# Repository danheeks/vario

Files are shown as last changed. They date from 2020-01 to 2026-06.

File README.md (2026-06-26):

# vario
  
paragliding vario with arduino nano, piezo sounder, bmp280 altimeter, 9V battery  
https://www.youtube.com/watch?v=9QVq33m_nv8

Instructions here https://github.com/danheeks/vario/tree/master/bmp280piezo <br />
One battery lasted me two summers of amateur paragliding, maybe 50hrs, including a flight of 202km in the UK! <br />
https://youtu.be/KGif6ZkmjKs?t=256  

You can buy a kit to make your own for £10, doesn't include postage

It includes: <br />
 <br />
Tin <br />
Arduino Nano <br />
BMP280 sensor <br />
Piezo Buzzer ( passive not active ) <br />
9V PP3 battery <br />
battery connector and wires <br />
On/Off switch <br />
version 7 PCB ( currently waiting for an order, available around 20th June 2026 ) <br />
Sticker for front of tin <br />
 <br />
Or you can buy a working vario £20, doesnt' include postage, ( I have 2 in stock 6th June 2026 ). <br />
 <br />
Email danheeks@gmail.com for enquiries and to check on stock <br />
  
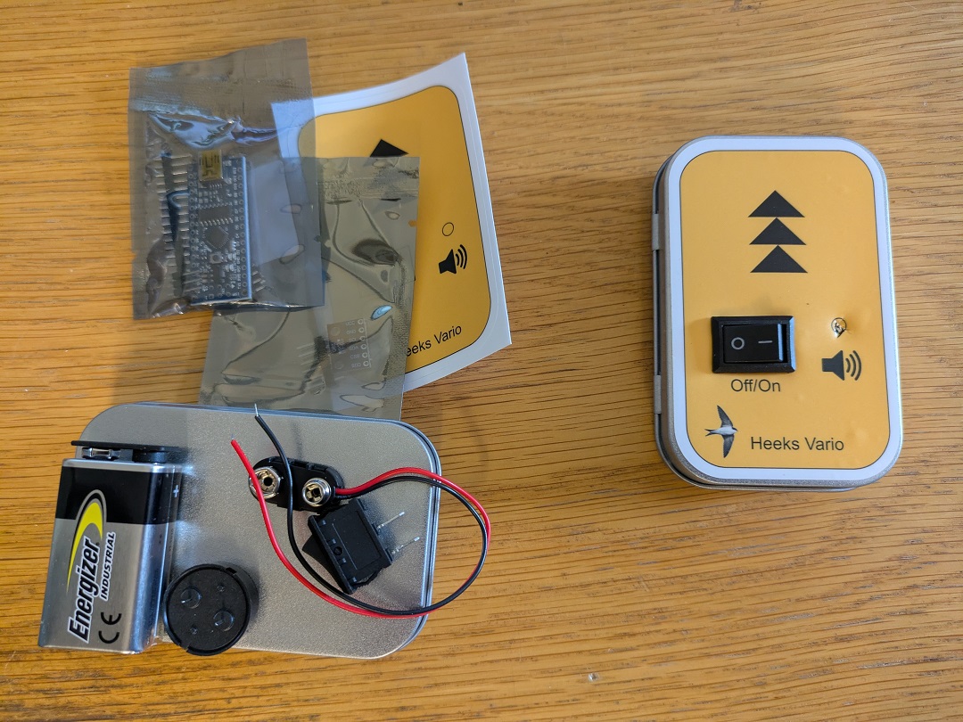
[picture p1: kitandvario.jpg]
Schematic Picture


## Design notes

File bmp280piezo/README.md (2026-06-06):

Vario using BMP280

Items needed

- Tin
- Arduino Nano
- BMP280 sensor
- Piezo Buzzer ( passive not active )
- 9V PP3 battery
- On/Off switch
- some wire

Wiring.

- Arduino GND to BMP280 GND
- Arduino 3.3V to BMP280 VDD
- Arduino A5 to BMP280 SCL
- Arduino A4 to BMP280 SDA
- Arduino D9 and D10 to the Piezo Buzzer ( see toneAC.h )
- Arduino VIN to battery + ( via on/off switch )
- Arduino GND to battery -

I measured 10mA standby current, so should theoretically last 55 hours.
One battery lasted me two summers of amateur paragliding, maybe 50hrs, including a flight of 202km in the UK! <br />
https://youtu.be/KGif6ZkmjKs?t=256  

Video of how to make this vario <br />
https://youtu.be/9QVq33m_nv8

Schematic Picture

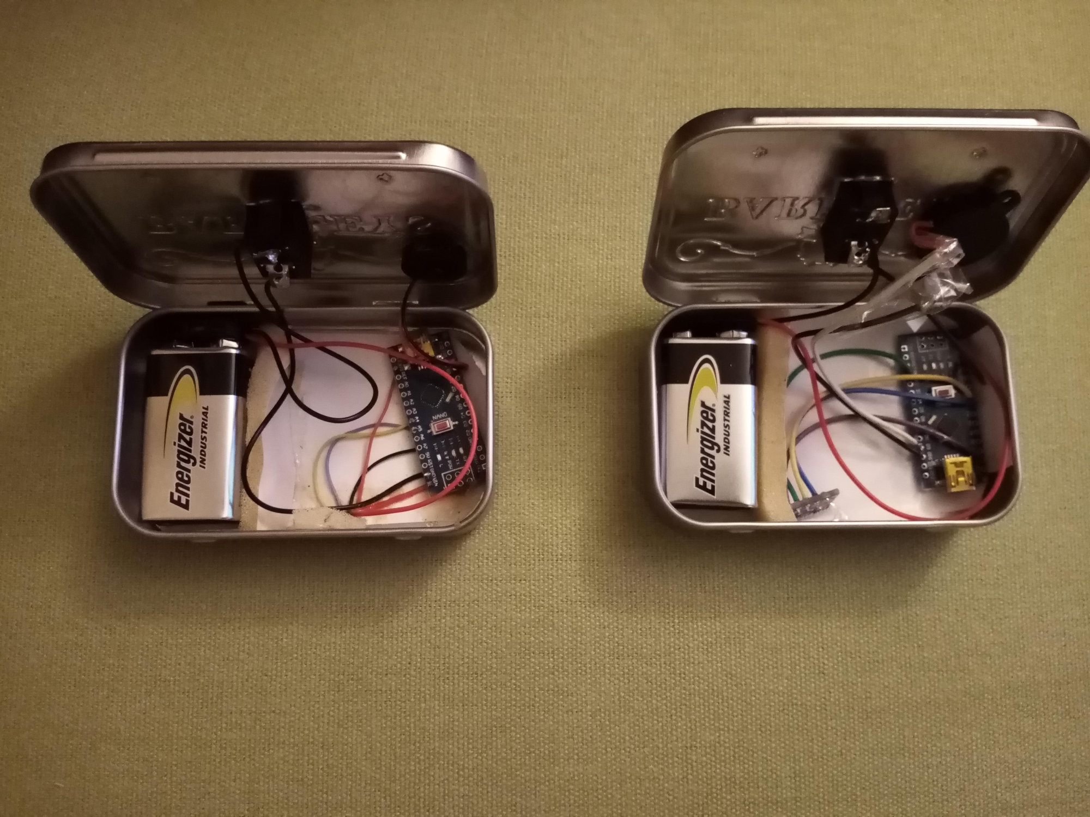
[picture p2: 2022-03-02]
variosopen.jpg

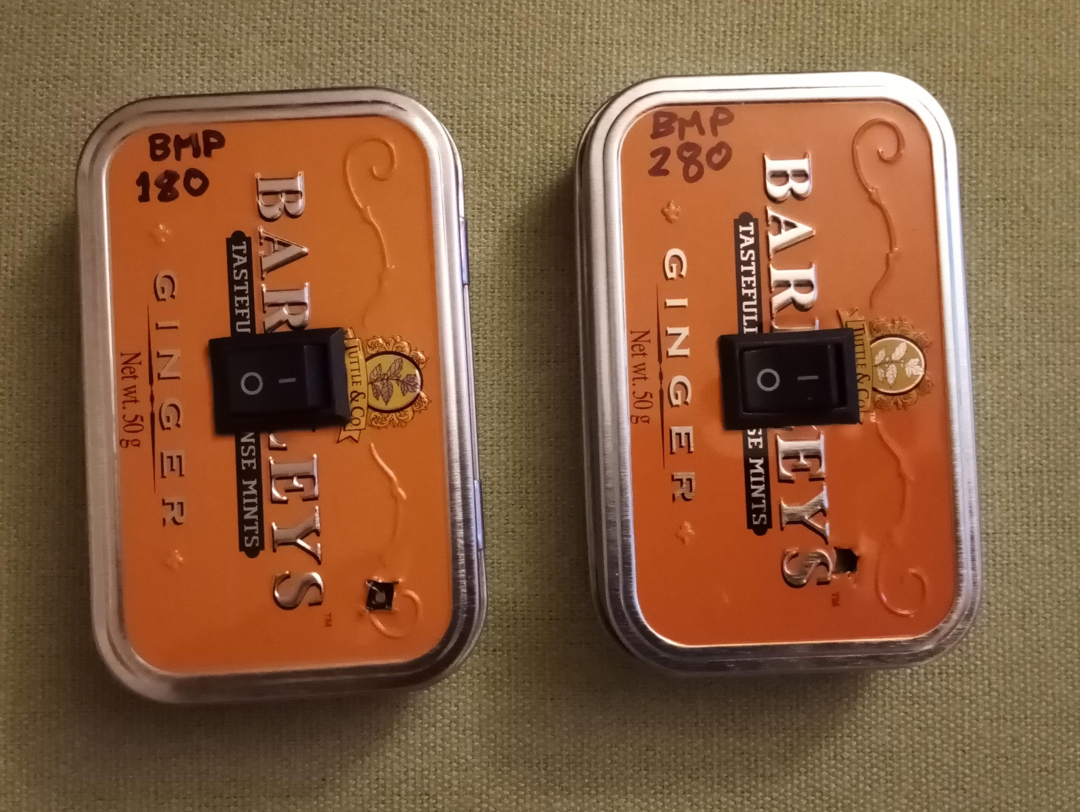
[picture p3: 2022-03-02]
varios.jpg

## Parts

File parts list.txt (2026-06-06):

Arduino Nano   £1.81
10PCS 35mm Piezo Elements buzzer Sounder   £0.25
BMP180        £1.00
on/off switch  £0.15
battery contacts £0.23
50g PLA

https://www.ebay.co.uk/itm/100-Pcs-Metal-Battery-Spring-Plate-Set-for-AA-AAA-Positive-Negative-Contact-r/143408425298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

and 

https://www.ebay.co.uk/itm/264527084049

total £3.78

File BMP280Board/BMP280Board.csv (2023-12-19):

# | Reference | Qty | Value | Footprint | DNP
1 | A1 | 1 | Arduino_Nano | Module:Arduino_Nano_WithMountingHoles
2 | C1, C2 | 2 | 100nF | Capacitor_SMD:CP_Elec_6.3x3.9
3 | R1, R2, R3, R4 | 4 | 10k | Resistor_SMD:R_0201_0603Metric
4 | U1 | 1 | BMP280 | Package_LGA:Bosch_LGA-8_2x2.5mm_P0.65mm_ClockwisePinNumbering

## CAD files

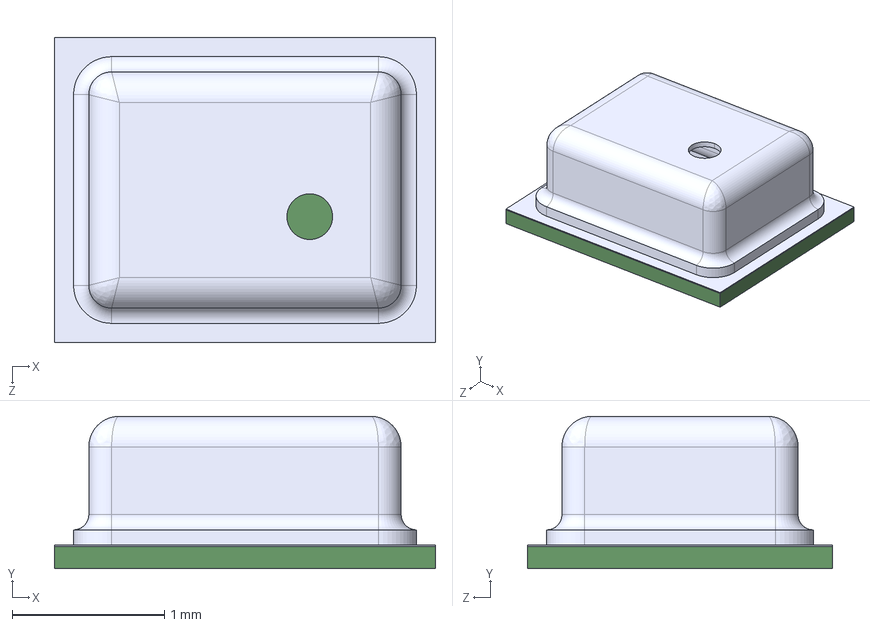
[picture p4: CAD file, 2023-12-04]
BMP280Board/BMP280/BMP280.step
2.50 x 1.00 x 2.00 mm

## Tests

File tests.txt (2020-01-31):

22-01-2020 Current draw 11.8mA
remove Serial calls
Current draw 11.7mA
removed the power led
current draw 9.8mA

added code: LowPower.powerDown(SLEEP_FOREVER, ADC_OFF, BOD_OFF);
current draw 1.4mA ( useless though :) )

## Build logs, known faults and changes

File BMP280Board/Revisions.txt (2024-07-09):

PCB ordered 8th Dec 2023
  Pads for resistors and capacitors were wrongly specified as "0201_0603Metric", when they should have been "0603_1608Metric_Pad0.98x0.95mm_HandSolder"
    ( the footprint had "0603" in the title, which is what I was looking for. I hadn't realized that the first number is inch, the second is mm )
  I had wrongly connected A4 ( SDA ) on Nano to SDO on BMP280. It should have been connected to SDI on BMP280.
  Likewise SDI was wrongly connected to a pull down to GND, but it should have been SDO getting pulled down to GND.
  I had connected a capacitor between A4 on Nano and GND, but it should have been connected between V3.3 and GND somewhere near the BMP280.
  I'd like to convert the footprint for the BMP280 to a hand solder footprint.
  The sensor was working, but the pressure change seemed a bit rubbish; I had to ascend the stairs at a run to get beeping. Damaged by the hot air gun or the flux maybe?

v2 PCB ordered 25th Dec 2023
   Assembled it 8th Jan 2024. Not working yet.

v3 
  Changed back to original sensor footprint, but had wrong wiring of sensor

v4 PCB orodered 27th Jan 2024
  I got one working and made a working vario. :) 
  Only of one the four boards that I made worked, though :(

v5
  switch to Attiny85

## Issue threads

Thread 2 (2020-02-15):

Wiring

m00nsp3ll, 2020-02-15:
Hello,
im going to build your vario but i need wiring scheme. Could you please share it.

Regards,

danheeks, 2020-02-15:
see in  vario/bmp180piezo/bmp180piezo.ino

/*
Hardware connections:
- (GND) to GND
+ (VDD) to 3.3V
SCL to A5
SDA to A4
*/

Also, I am connecting 3 x AA alkaline batteries via an on/off swithch to the 5V and GND on the arduino nano.

Is this enough?

m00nsp3ll, 2020-02-16:
thank you for the reply,

which pins should i wire the Piezo buzzer.

Regards,

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

--
Harun Sivaslı

danheeks, 2020-02-16:
D9 and D10 to the Piezo Buzzer.
I've just added a comment to the source code.

m00nsp3ll, 2020-02-16:
thank you very much,
i am going to build it and test.

regards

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

--
Harun Sivaslı

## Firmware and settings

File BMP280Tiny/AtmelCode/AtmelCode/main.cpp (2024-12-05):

// main.cpp Dan Heeks 20th October 2024
#include <avr/io.h>
#include <avr/interrupt.h>
#include <avr/sleep.h>
#include <avr/wdt.h>

// PIEZO_PINA PB1
// PIEZO_PINB PB2

#define SET_PIEZ0_A PORTB |= 0x02;
#define SET_PIEZ0_B PORTB |= 0x04;
#define CLR_PIEZ0_A PORTB &= 0xfd;
#define CLR_PIEZ0_B PORTB &= 0xfb;

#define F_CPU 8000000UL  // Set clock frequency to 8 MHz

#define BMP_280_ADDR 0x76

int delay_a = 0;
void delay(uint16_t ms)
{
	uint32_t i;
	uint32_t length = ms;
	length *= 600;
	
	for(i = 0; i<length; i++)
	{
		delay_a = 1;
	}
}

volatile uint16_t remaining_ms = 0;  // Variable to track the remaining delay time

// Watchdog Interrupt Service Routine (ISR)
ISR(WDT_vect) {
	if (remaining_ms >= 16) {
		remaining_ms -= 16;  // Decrease remaining time by 16 ms (WDT interval)
		} else {
		remaining_ms = 0;    // Ensure it doesn't go below zero
	}
}

void delay_ms(uint16_t ms) {
    remaining_ms = ms;

    // Set up the Watchdog Timer for 16 ms interrupts
    cli();  // Disable interrupts while configuring the WDT

    // Enable change of WDT settings
    wdt_reset();  // Reset the WDT
    MCUSR &= ~(1 << WDRF);  // Clear WDT reset flag
    WDTCSR |= (1 << WDCE) | (1 << WDE);  // Enable timed sequence for changing WDT settings

    // Set WDT to interrupt mode only, with the 16 ms timeout
    WDTCSR = (1 << WDIE);  // Set WDP0 = 0 (default), enabling the 16 ms timeout, enable WDT interrupt

    sei();  // Re-enable global interrupts

    // Enter low-power mode and wait for the delay to finish
    while (remaining_ms > 0) {
	    set_sleep_mode(SLEEP_MODE_IDLE);  // Power-down mode
	    sleep_mode();  // Go to sleep until WDT interrupt occurs
    }

    // Disable the Watchdog Timer after the delay is finished
    cli();
    wdt_reset();  // Reset the WDT again
    WDTCSR |= (1 << WDCE) | (1 << WDE);  // Enter WDT configuration mode
    WDTCSR = 0x00;  // Disable the WDT
    sei();  // Re-enable global interrupts
}

void led1_on()
{
	PORTB |= 0x20; // led1 on
}

void led1_off()
{
	PORTB &= 0xdf; // led1 off
}

void led2_on()
{
	PORTB |= 0x01; // led2 on
}

void led2_off()
{
	PORTB &= 0xfe; // led2 off
}

void flash_led1(uint16_t ms)
{
	led1_on();
	delay(ms);
	led1_off();	
}

void flash_led2(uint16_t ms)
{
	led2_on();
	delay(ms);
	led2_off();
}

void inline sleep_us(int8_t iD) {
	asm(
	"mov r25, %0 ; \n"
	"1: \n"
	"dec r25 \n"
	"nop  \n"
	"brne 1b \n"
	:
	: "r" (iD)
	: "r25" );
}

#define I2C_DELAY      sleep_us(5);


#define SDA_PIN PC4
#define SCL_PIN PC5

// Set SDA and SCL as inputs (high impedance) for HIGH state
#define I2C_SET_SDA     {DDRC &= 0xef;  PORTC |= 0x10;}// Set SDA as input
#define I2C_SET_SCL     {DDRC &= 0xdf;  PORTC |= 0x20;}  // Set SCL as input

// Set SDA and SCL as outputs and drive low
#define I2C_CLR_SDA      {DDRC |= 0x10; PORTC &= 0xef;}
#define I2C_CLR_SCL      {DDRC |= 0x20; PORTC &= 0xdf;}

void toneAC(uint16_t frequency) {
	// Calculate the value for the Output Compare Register
	uint16_t ocr_value = (F_CPU / (2 * frequency)) - 1;

	// Set PB1 and PB2 as output
	DDRB |= (1 << PB1) | (1 << PB2);
	PORTB |= (1 << PB1);

	// Set Timer1 in CTC mode
	TCCR1A = 0;  // Normal port operation, OC1A/OC1B disconnected
	TCCR1B = (1 << WGM12) | (1 << CS10);  // CTC mode, no prescaler

	// Set compare value
	OCR1A = ocr_value;

	// Enable Output Compare A Match Interrupt
	TIMSK1 |= (1 << OCIE1A);
}

void stop_tone() {
	TCCR1B &= ~(1 << CS10);  // Stop the timer (no clock source)
}

void beep(uint16_t frequency, uint16_t time_ms)
{
	toneAC(frequency);
	delay(time_ms);
	stop_tone();
}

uint8_t tone_count = 0;

ISR(TIMER1_COMPA_vect) {
	// Toggle PB1 and PB2 on every compare match to create the tone
	if(tone_count == 0)
	{
		PORTB |= 0b00000010;
		PORTB &= 0b11111110;
		tone_count = 1;
	}
	else
	{
		PORTB |= 0b00000001;
		PORTB &= 0b11111101;
		tone_count = 0;
	}
}

// Generate a START condition
void i2c_start_condition( void )
{
	I2C_CLR_SDA
	I2C_DELAY
	I2C_CLR_SCL
	I2C_DELAY
}

// Generate a STOP condition
void i2c_stop_condition( void )
{
	I2C_CLR_SDA
	I2C_DELAY
	I2C_SET_SCL
	I2C_DELAY
	I2C_SET_SDA
	I2C_DELAY
}

bool i2c_write_uint8_t( uint8_t B )
{
	uint8_t ack = 0;

	uint8_t i;
	for( i = 0; i < 8; i++ )
	{
		if(B & 0x80) I2C_SET_SDA
		else I2C_CLR_SDA
		B <<= 1;

		I2C_DELAY
		I2C_SET_SCL
		I2C_DELAY
		I2C_CLR_SCL
		I2C_DELAY
	}
	
	I2C_SET_SDA
	//I2C_DELAY
	I2C_SET_SCL
	I2C_DELAY
	
	if( (PINC & 0x10) == 0x00 ) ack = 1;
	else ack = 0;

	I2C_CLR_SCL
	
	return ack;
}

uint8_t i2c_read_uint8_t( bool ack )
{
	uint8_t data = 0;
	I2C_SET_SDA

	for( uint8_t i = 0; i < 8; i++ )
	{
		data <<= 1;
	    do{
		   I2C_SET_SCL
	    }while((PINC & 0x20) == 0);  //clock stretching	I2C_DELAY
		I2C_DELAY
		if((PINC & 0x10)!=0)data |= 1;
		I2C_DELAY
		I2C_CLR_SCL
	}

	if( ack ) I2C_CLR_SDA
	else I2C_SET_SDA
	I2C_SET_SCL
	I2C_DELAY
	I2C_CLR_SCL
	I2C_SET_SDA

	return data;
}

uint8_t calculate_crc(uint8_t* data, uint16_t length) {
	uint8_t crc = 0xFF;  // Initial CRC value
	for (uint16_t i = 0; i < length; i++) {
		crc ^= data[i];
		for (uint8_t j = 0; j < 8; j++) {
			if (crc & 0x80) {
				crc = (crc << 1) ^ 0x31;
				} else {
				crc <<= 1;
			}
		}
	}
	return crc;
}

int8_t i2c_write(const uint8_t* data, uint16_t count, bool appendCrc) {

	i2c_start_condition();
	
	if (!i2c_write_uint8_t(BMP_280_ADDR << 1)) {  // Write mode
		flash_led2(1000);
		i2c_stop_condition();
		return -1;  // Error: No ACK from sensor
	}

	for (uint16_t i = 0; i < count; i++) {
		if (!i2c_write_uint8_t(data[i])) {  // Send each uint8_t
			i2c_stop_condition();
			flash_led2(100);
			return -1;  // Error: No ACK from sensor
		}

		// If appendCrc is true, calculate and send the CRC after each block of data
		if (appendCrc) {
			uint8_t crc = calculate_crc((uint8_t*)&data[i], 1);  // CRC for one uint8_t at a time
			if (!i2c_write_uint8_t(crc)) {  // Send CRC uint8_t
				i2c_stop_condition();
				flash_led2(2000);
				return -1;  // Error: No ACK from sensor
			}
		}
	}

	i2c_stop_condition();
	return 0;  // Success
}

int8_t i2c_read(uint8_t* data, uint16_t count) {
	
	i2c_start_condition();
	if (!i2c_write_uint8_t((BMP_280_ADDR << 1) | 1)) {  // Send address with read bit (last bit 1)
		i2c_stop_condition();
		flash_led2(100);
		delay(100);
		flash_led2(100);
		delay(100);
		flash_led2(100);
		delay(100);
		flash_led2(100);
		delay(100);
		flash_led2(100);
		delay(100);
		return -1;  // Error: No ACK from sensor
	}
	
	for (uint16_t i = 0; i < count - 1; i++) {
		data[i] = i2c_read_uint8_t(true);  // Read uint8_t with ACK (acknowledge)
	}

	data[count - 1] = i2c_read_uint8_t(false);  // Read the last uint8_t with NACK (no acknowledge)

	i2c_stop_condition();
	return 0;  // Success
}

void tone(uint16_t frequency, uint16_t duration_ms) {
	// Set PB1 and PB2 as outputs
	DDRB |= (1 << PB1) | (1 << PB2);

	// Set Fast PWM mode, non-inverted output on OC1A (PB1) and OC1B (PB2)
	TCCR1A |= (1 << COM1A0) | (1 << COM1B0);  // Toggle OC1A/OC1B on compare match
	TCCR1A |= (1 << WGM10);  // Fast PWM 8-bit
	TCCR1B |= (1 << WGM12) | (1 << CS10);  // Fast PWM, no prescaling

	// Calculate the OCR1A value for the desired frequency
	uint16_t ocr_value = (F_CPU / (2 * frequency)) - 1;
	OCR1A = ocr_value;  // Set the value to Timer1 for the frequency
	OCR1B = ocr_value;  // Set OC1B to mirror OC1A (for PB2)

	// Generate the tone for the specified duration
	for (uint16_t i = 0; i < duration_ms; i++) {
		delay(1);
	}

	// Stop the timer after the tone is played
	TCCR1A = 0;  // Clear the Timer1 control registers
	TCCR1B = 0;
	PORTB &= ~((1 << PB1) | (1 << PB2));  // Turn off the buzzer
}


uint8_t bmp_init()
{
	i2c_start_condition();
	
	if (!i2c_write_uint8_t(0x76 << 1)) {  // Write mode
		i2c_stop_condition();
		return 0;  // Error: No ACK from sensor
	}
	
	i2c_stop_condition();
	return 1;  // Success
}


/*!
 * Registers available on the sensor.
 */
enum {
  BMP280_REGISTER_DIG_T1 = 0x88,
  BMP280_REGISTER_DIG_T2 = 0x8A,
  BMP280_REGISTER_DIG_T3 = 0x8C,
  BMP280_REGISTER_DIG_P1 = 0x8E,
  BMP280_REGISTER_DIG_P2 = 0x90,
  BMP280_REGISTER_DIG_P3 = 0x92,
  BMP280_REGISTER_DIG_P4 = 0x94,
  BMP280_REGISTER_DIG_P5 = 0x96,
  BMP280_REGISTER_DIG_P6 = 0x98,
  BMP280_REGISTER_DIG_P7 = 0x9A,
  BMP280_REGISTER_DIG_P8 = 0x9C,
  BMP280_REGISTER_DIG_P9 = 0x9E,
  BMP280_REGISTER_CHIPID = 0xD0,
  BMP280_REGISTER_VERSION = 0xD1,
  BMP280_REGISTER_SOFTRESET = 0xE0,
  BMP280_REGISTER_CAL26 = 0xE1, /**< R calibration = 0xE1-0xF0 */
  BMP280_REGISTER_STATUS = 0xF3,
  BMP280_REGISTER_CONTROL = 0xF4,
  BMP280_REGISTER_CONFIG = 0xF5,
  BMP280_REGISTER_PRESSUREDATA = 0xF7,
  BMP280_REGISTER_TEMPDATA = 0xFA,
};

  /** Oversampling rate for the sensor. */
  enum sensor_sampling {
    /** No over-sampling. */
    SAMPLING_NONE = 0x00,
    /** 1x over-sampling. */
    SAMPLING_X1 = 0x01,
    /** 2x over-sampling. */
    SAMPLING_X2 = 0x02,
    /** 4x over-sampling. */
    SAMPLING_X4 = 0x03,
    /** 8x over-sampling. */
    SAMPLING_X8 = 0x04,
    /** 16x over-sampling. */
    SAMPLING_X16 = 0x05
  };

  /** Operating mode for the sensor. */
  enum sensor_mode {
    /** Sleep mode. */
    MODE_SLEEP = 0x00,
    /** Forced mode. */
    MODE_FORCED = 0x01,
    /** Normal mode. */
    MODE_NORMAL = 0x03,
    /** Software reset. */
    MODE_SOFT_RESET_CODE = 0xB6
  };

  /** Filtering level for sensor data. */
  enum sensor_filter {
    /** No filtering. */
    FILTER_OFF = 0x00,
    /** 2x filtering. */
    FILTER_X2 = 0x01,
    /** 4x filtering. */
    FILTER_X4 = 0x02,
    /** 8x filtering. */
    FILTER_X8 = 0x03,
    /** 16x filtering. */
    FILTER_X16 = 0x04
  };

  /** Standby duration in ms */
  enum standby_duration {
    /** 1 ms standby. */
    STANDBY_MS_1 = 0x00,
    /** 62.5 ms standby. */
    STANDBY_MS_63 = 0x01,
    /** 125 ms standby. */
    STANDBY_MS_125 = 0x02,
    /** 250 ms standby. */
    STANDBY_MS_250 = 0x03,
    /** 500 ms standby. */
    STANDBY_MS_500 = 0x04,
    /** 1000 ms standby. */
    STANDBY_MS_1000 = 0x05,
    /** 2000 ms standby. */
    STANDBY_MS_2000 = 0x06,
    /** 4000 ms standby. */
    STANDBY_MS_4000 = 0x07
  };

  /** Encapsulates the config register */
  struct config {
    /** Initialize to power-on-reset state */
    config() : t_sb(STANDBY_MS_1), filter(FILTER_OFF), none(0), spi3w_en(0) {}
    /** Inactive duration (standby time) in normal mode */
    unsigned int t_sb : 3;
    /** Filter settings */
    unsigned int filter : 3;
    /** Unused - don't set */
    unsigned int none : 1;
    /** Enables 3-wire SPI */
    unsigned int spi3w_en : 1;
    /** Used to retrieve the assembled config register's uint8_t value. */
    unsigned int get() { return (t_sb << 5) | (filter << 2) | spi3w_en; }
  };

  /** Encapsulates trhe ctrl_meas register */
  struct ctrl_meas {
    /** Initialize to power-on-reset state */
    ctrl_meas()
        : osrs_t(SAMPLING_NONE), osrs_p(SAMPLING_NONE), mode(MODE_SLEEP) {}
    /** Temperature oversampling. */
    unsigned int osrs_t : 3;
    /** Pressure oversampling. */
    unsigned int osrs_p : 3;
    /** Device mode */
    unsigned int mode : 2;
    /** Used to retrieve the assembled ctrl_meas register's uint8_t value. */
    unsigned int get() { return (osrs_t << 5) | (osrs_p << 2) | mode; }
  };

typedef struct {
  uint16_t dig_T1; /**< dig_T1 cal register. */
  int16_t dig_T2;  /**<  dig_T2 cal register. */
  int16_t dig_T3;  /**< dig_T3 cal register. */

  uint16_t dig_P1; /**< dig_P1 cal register. */
  int16_t dig_P2;  /**< dig_P2 cal register. */
  int16_t dig_P3;  /**< dig_P3 cal register. */
  int16_t dig_P4;  /**< dig_P4 cal register. */
  int16_t dig_P5;  /**< dig_P5 cal register. */
  int16_t dig_P6;  /**< dig_P6 cal register. */
  int16_t dig_P7;  /**< dig_P7 cal register. */
  int16_t dig_P8;  /**< dig_P8 cal register. */
  int16_t dig_P9;  /**< dig_P9 cal register. */
} bmp280_calib_data;

int32_t t_fine;
bmp280_calib_data _bmp280_calib;
float prev_p = 0;
config _configReg;
ctrl_meas _measReg;
  
uint8_t write_then_read(const uint8_t *write_buffer, uint8_t write_len, uint8_t *read_buffer, uint8_t read_len) {
	if (i2c_write(write_buffer, write_len, false) != 0) {
		beep(300,500);
		return false;
	}

	return i2c_read(read_buffer, read_len);
}


uint8_t read8(uint8_t reg) {
  uint8_t buffer[1];
  buffer[0] = uint8_t(reg);
  write_then_read(buffer, 1, buffer, 1);
  return buffer[0];
}

void write8(uint8_t reg, uint8_t value) {
  uint8_t buffer[2];
  buffer[1] = value;
  buffer[0] = reg;
  i2c_write(buffer, 2, false);
}

uint32_t read24(uint8_t reg) {
  uint8_t buffer[3];

  buffer[0] = uint8_t(reg);
  
  write_then_read(buffer, 1, buffer, 3);
  
  return uint32_t(buffer[0]) << 16 | uint32_t(buffer[1]) << 8 |
         uint32_t(buffer[2]);
}

uint16_t read16(uint8_t reg) {
  uint8_t buffer[2];

    buffer[0] = uint8_t(reg);
    write_then_read(buffer, 1, buffer, 2);
  return uint16_t(buffer[0]) << 8 | uint16_t(buffer[1]);
}

uint16_t read16_LE(uint8_t reg) {
  uint16_t temp = read16(reg);
  return (temp >> 8) | (temp << 8);
}

int16_t readS16_LE(uint8_t reg) {
  return (int16_t)read16_LE(reg);
}

void readCoefficients() {
  _bmp280_calib.dig_T1 = read16_LE(BMP280_REGISTER_DIG_T1);
  _bmp280_calib.dig_T2 = readS16_LE(BMP280_REGISTER_DIG_T2);
  _bmp280_calib.dig_T3 = readS16_LE(BMP280_REGISTER_DIG_T3);

  _bmp280_calib.dig_P1 = read16_LE(BMP280_REGISTER_DIG_P1);
  _bmp280_calib.dig_P2 = readS16_LE(BMP280_REGISTER_DIG_P2);
  _bmp280_calib.dig_P3 = readS16_LE(BMP280_REGISTER_DIG_P3);
  _bmp280_calib.dig_P4 = readS16_LE(BMP280_REGISTER_DIG_P4);
  _bmp280_calib.dig_P5 = readS16_LE(BMP280_REGISTER_DIG_P5);
  _bmp280_calib.dig_P6 = readS16_LE(BMP280_REGISTER_DIG_P6);
  _bmp280_calib.dig_P7 = readS16_LE(BMP280_REGISTER_DIG_P7);
  _bmp280_calib.dig_P8 = readS16_LE(BMP280_REGISTER_DIG_P8);
  _bmp280_calib.dig_P9 = readS16_LE(BMP280_REGISTER_DIG_P9);
}

void setSampling()
{
  _measReg.mode = MODE_NORMAL;
  _measReg.osrs_t = SAMPLING_X2;
  _measReg.osrs_p = SAMPLING_X16;

  _configReg.filter = FILTER_X16;
  _configReg.t_sb = STANDBY_MS_63;

  write8(BMP280_REGISTER_CONFIG, _configReg.get());
  write8(BMP280_REGISTER_CONTROL, _measReg.get());
}

float readTemperature() {
  int32_t var1, var2;

  int32_t adc_T = read24(BMP280_REGISTER_TEMPDATA);
  
  adc_T >>= 4;

  var1 = ((((adc_T >> 3) - ((int32_t)_bmp280_calib.dig_T1 << 1))) *
          ((int32_t)_bmp280_calib.dig_T2)) >>
         11;

  var2 = (((((adc_T >> 4) - ((int32_t)_bmp280_calib.dig_T1)) *
            ((adc_T >> 4) - ((int32_t)_bmp280_calib.dig_T1))) >>
           12) *
          ((int32_t)_bmp280_calib.dig_T3)) >>
         14;

  t_fine = var1 + var2;

  float T = (t_fine * 5 + 128) >> 8;
  return T / 100;
}

float readPressure() {
  int64_t var1, var2, p;

  // Must be done first to get the t_fine variable set up
  readTemperature();

  int32_t adc_P = read24(BMP280_REGISTER_PRESSUREDATA);
  adc_P >>= 4;

  var1 = ((int64_t)t_fine) - 128000;
  var2 = var1 * var1 * (int64_t)_bmp280_calib.dig_P6;
  var2 = var2 + ((var1 * (int64_t)_bmp280_calib.dig_P5) << 17);
  var2 = var2 + (((int64_t)_bmp280_calib.dig_P4) << 35);
  var1 = ((var1 * var1 * (int64_t)_bmp280_calib.dig_P3) >> 8) +
         ((var1 * (int64_t)_bmp280_calib.dig_P2) << 12);
  var1 =
      (((((int64_t)1) << 47) + var1)) * ((int64_t)_bmp280_calib.dig_P1) >> 33;

  if (var1 == 0) {
    return 0; // avoid exception caused by division by zero
  }
  p = 1048576 - adc_P;
  p = (((p << 31) - var2) * 3125) / var1;
  var1 = (((int64_t)_bmp280_calib.dig_P9) * (p >> 13) * (p >> 13)) >> 25;
  var2 = (((int64_t)_bmp280_calib.dig_P8) * p) >> 19;

  p = ((p + var1 + var2) >> 8) + (((int64_t)_bmp280_calib.dig_P7) << 4);
  return (float)p / 256;
}

int main(void)
{
	DDRB = 0x27; // set piezo pins as outputs, also LEDs
	// B0 - 1 - LED2
	// B1 - 2 - Piezo
	// B2 - 4 - Piezo
	// B3 - 8 - MOSI
	// B4 - 10 - MISO
	// B5 - 20 - SCK and LED1
	// B6 - 40 - Not Used
	// B7 - 80 - Not Used
	
	PORTB &= 0xf7;
	PORTB = 0;

    // Enable global interrupts for the tone timer
    sei();
	
	beep(388, 70);
	delay_ms(1000);
	beep(590, 70);

	delay(500); // wait for sensor to settle

	// try init 10 times	
	for(int i = 0; i<10; i++)
	{
		if(bmp_init())
			break;

		if(i == 9)
		{
			beep(300,1000); // failed and giving up sound
			return 0;
		}
		beep(300,100); // failed sound
	}

	// i2c has acknowledged sensor's address
	beep(800, 100); // success sound
	
	readCoefficients();
	
	float prev_pressure = readPressure();

	setSampling();
  
	while(1)
	{
		float pressure = readPressure();
		float rate = (pressure - prev_pressure) * 15.0;
		prev_pressure = pressure;
		if(rate < -10)
		{
			float pitch = 500.0 - (rate * 10.0);
			if(pitch > 2000)pitch = 2000;
			toneAC((float)pitch);
			delay_ms(120);
			stop_tone();
			delay_ms(120);
		}
		else if(rate>30)
		{
			toneAC(300);
			delay_ms(250);
		}
		else
		{
			stop_tone();
			delay_ms(250);
		}		
	}
}

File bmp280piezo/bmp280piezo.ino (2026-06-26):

#include <toneAC.h> // by Tim Eckel
#include <Wire.h>
#include <Adafruit_BMP280.h> // by Adafruit
#include <LowPower.h> // by LowPowerLab

Adafruit_BMP280 bmp; // use I2C interface
Adafruit_Sensor *bmp_pressure = bmp.getPressureSensor();
/*
Hardware connections:

- (GND) to GND
+ (VDD) to 3.3V
SCL to A5
SDA to A4

D9 and D10 to the Piezo Buzzer ( see toneAC.h )

*/

float old_pressure = 0;

void setup() {
  Serial.begin(9600);
// play start sound
   toneAC(388, 4);
  delay(70);
  unsigned status;
  status = bmp.begin(0x76);
  Serial.println(status);
  if(!status)
  {
    toneAC(250, 10);
    delay(150);
    toneAC(0);
    delay(150);
    toneAC(250, 10);
    delay(150);
    toneAC(0);
    delay(150);
    toneAC(250, 10);
    delay(150);
    toneAC(0);
    delay(150);
  }

  /* Default settings from datasheet. */
  bmp.setSampling(Adafruit_BMP280::MODE_NORMAL,     /* Operating Mode. */
                  Adafruit_BMP280::SAMPLING_X2,     /* Temp. oversampling */
                  Adafruit_BMP280::SAMPLING_X16,    /* Pressure oversampling */
                  Adafruit_BMP280::FILTER_X16,      /* Filtering. */
                  Adafruit_BMP280::STANDBY_MS_63); /* Standby time. */

  sensors_event_t pressure_event;
  bmp_pressure->getEvent(&pressure_event);
  
  old_pressure = pressure_event.pressure;
  
  toneAC(590, 4);
  delay(70);
  toneAC(0);
}

void loop(){
  sensors_event_t pressure_event;
  bmp_pressure->getEvent(&pressure_event);
  
  float new_pressure = pressure_event.pressure;
  float rate = (new_pressure - old_pressure) * 1000.0;
  old_pressure = new_pressure;

  Serial.println((int)rate);

  if(rate<-8)
  {
  float pitch = 500.0 - (rate * 10.0);
  if(pitch > 2500)pitch = 2500.0;
  toneAC((unsigned int)pitch);
  LowPower.idle(SLEEP_120MS, ADC_OFF, TIMER2_OFF, TIMER1_ON, TIMER0_OFF, SPI_OFF,USART0_OFF, TWI_OFF);
//    delay(120);
  toneAC(0);
  LowPower.idle(SLEEP_120MS, ADC_OFF, TIMER2_OFF, TIMER1_ON, TIMER0_OFF, SPI_OFF,USART0_OFF, TWI_OFF);
//    delay(120);
  }
  else if(rate>30)
  {
    toneAC(300, 1);
    LowPower.idle(SLEEP_250MS, ADC_OFF, TIMER2_OFF, TIMER1_ON, TIMER0_OFF, SPI_OFF,USART0_OFF, TWI_OFF);
//    delay(250);
  }
  else
  {
    toneAC(0);
    LowPower.idle(SLEEP_250MS, ADC_OFF, TIMER2_OFF, TIMER1_ON, TIMER0_OFF, SPI_OFF,USART0_OFF, TWI_OFF);
    //delay(250);
  }
}

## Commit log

2020-01-08 added arduino code and parts list
2020-01-22 I changed the start tone to a short bi-beep
    [bmp180piezo.ino]
2020-01-31 removed Serial calls, to lower current draw ( stops an LED flashing )
2020-02-16 added comment about which pins the piezo buzzer is connected to.
    [bmp180piezo.ino]
2021-03-14 more pitch effect
2021-11-12 work on a schematic.svg
2021-11-17 added bmp180 schematic.svg
2022-02-13 added BMP280 schematic and README.md
2022-02-21 added a tin to the schematic picture
2022-05-15 I made the climb rate go higher. I made the sink alarm less sensitive. I removed the serial prints
2022-05-15 added empty project for designing a PCB
    [BMP280Board.kicad_pcb, BMP280Board.sch]
2022-05-16 kicad work on vario PCB. I don't know what I'm doing yet.
    [BMP280Board.kicad_pcb, BMP280Board.sch]
2023-12-04 upgraded to kicad 7
    [BMP280.step, BMP280Board.kicad_pcb, BMP280Board.kicad_sch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]
2023-12-19 work on BMP280Board
    [BMP280Board.csv, BMP280Board.kicad_pcb, BMP280Board.kicad_sch]
2023-12-21 fixed - piezo speaker was connected to pin 9 and pin 10, should have been connected to D9 and D10
    [BMP280Board.kicad_pcb, BMP280Board.kicad_sch]
2023-12-23 starting work on fixing problems found with 8th Dec 2023 revision
    [BMP280Board.kicad_pcb, BMP280Board.kicad_sch]
2023-12-24 starting on drawing v2 of schematic
    [BMP280Board.kicad_sch]
2023-12-24 still working on v2
    [BMP280Board.kicad_pcb, BMP280Board.kicad_sch]
2023-12-25 Tracks on v2
    [BMP280Board.kicad_pcb, BMP280Board.kicad_sch]
2023-12-25 submitted v2 of vario board
    [BMP280Board.kicad_pcb]
2024-01-18 I changed the footprint of the sensor back to the original one. I think the solder was touching the metal case of the solder, shorting the circuit
    [BMP280Board.kicad_pcb, BMP280Board.kicad_sch]
2024-01-28 I had updated the x4 pcb, but had forgotten to update the main pcb file
    [BMP280Board.kicad_pcb]
2024-07-08 Added BMP280Tiny, plus latest other board
    [BMP280Board.kicad_pcb, BMP280Board.kicad_sch, BMP280Tiny.kicad_pcb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]
2024-07-09 changes found on my works PC
    [BMP280Board.kicad_pcb, BMP280Board.kicad_sch]
2024-07-09 work on new vario board
    [BMP280Tiny.kicad_sch]
2024-07-11 work on attiny88 board schematic
    [BMP280Tiny.kicad_sch]
2024-07-12 Vario v5 sent to jlcpcb for production
    [BMP280Tiny.kicad_pcb, BMP280Tiny.kicad_sch]
2024-07-25 added Arduino Uno programmer.txt
2024-07-27 work on code for BMP280Tiny ( vario v5 ) board
2024-10-16 added i2c code with a beep
2024-10-20 experiments with simpler version of vario code to fit on Attiny88, it didn't really work properly
    [ArduinoCode.ino]
2024-12-05 work on vario board
    [BMP280Tiny.kicad_pcb, BMP280Tiny.kicad_sch]
2024-12-11 updated vario switch footpring
2024-12-11 vario v6
    [BMP280Board.kicad_pcb, BMP280Board.kicad_sch]
2025-06-09 I played with doing iron-on laser printer toner transfer onto tins
2025-07-29 I reinstated the low power delays.
2026-06-05 v7 of vario ( I moved to KiCad 10 )
    [BMP280Board.kicad_pcb, BMP280Board.kicad_sch]
2026-06-26 allow the pitch to go higher
